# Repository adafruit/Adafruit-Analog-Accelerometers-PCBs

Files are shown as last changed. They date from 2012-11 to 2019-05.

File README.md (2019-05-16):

# PCBs for the Adafruit Analog Accelerometers - ADXL335, ADXL377 and ADXL326

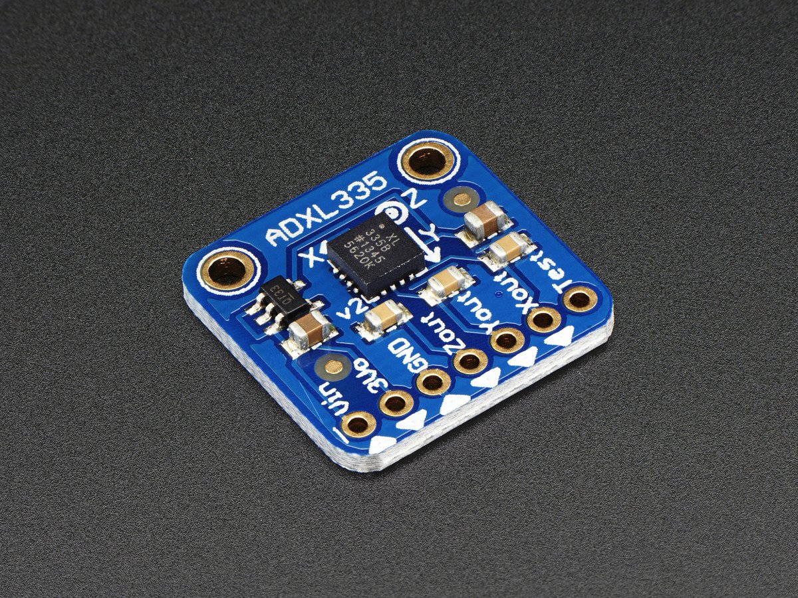
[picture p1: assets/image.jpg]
<a href="http://www.adafruit.com/products/163"><br/>Click here to purchase one from the Adafruit shop</a>

* [ADXL335 - 5V ready triple-axis accelerometer (+-3g analog out)](https://www.adafruit.com/products/163)
* [ADXL326 - 5V ready triple-axis accelerometer (+-16g analog out)](https://www.adafruit.com/product/1018)
* [ADXL377 - High-G Triple-Axis Accelerometer (+-200g Analog Out)](https://www.adafruit.com/product/1413)

We've updated our favorite triple-axis accelerometer to now have an on-board 3.3V regulator - making it a perfect choice for interfacing with a 5V microcontroller such as the Arduino. This breakout comes with 3 analog outputs for X, Y and Z axis measurements on a 0.75"x0.75" breakout board. The ADXL335 is the latest and greatest from Analog Devices, known for their exceptional quality MEMS devices. The VCC takes up to 5V in and regulates it to 3.3V with an output pin. The analog outputs are ratiometric: that means that 0g measurement output is always at half of the 3.3V output (1.65V), -3g is at 0v and 3g is at 3.3V with full scaling in between.

Fully assembled and tested. Comes with 8 pin 0.1" standard header in case you want to use it with a breadboard or perfboard. Two 2mm (0.08") mounting holes for easy attachment.

The XYZ filter capacitors are 0.1uF for a 50 Hz bandwidth

## License

Adafruit invests time and resources providing this open source design, 
please support Adafruit and open-source hardware by purchasing 
products from Adafruit!

Designed by Adafruit Industries.  
Creative Commons Attribution, Share-Alike license, check license.txt for more information
All text above must be included in any redistribution

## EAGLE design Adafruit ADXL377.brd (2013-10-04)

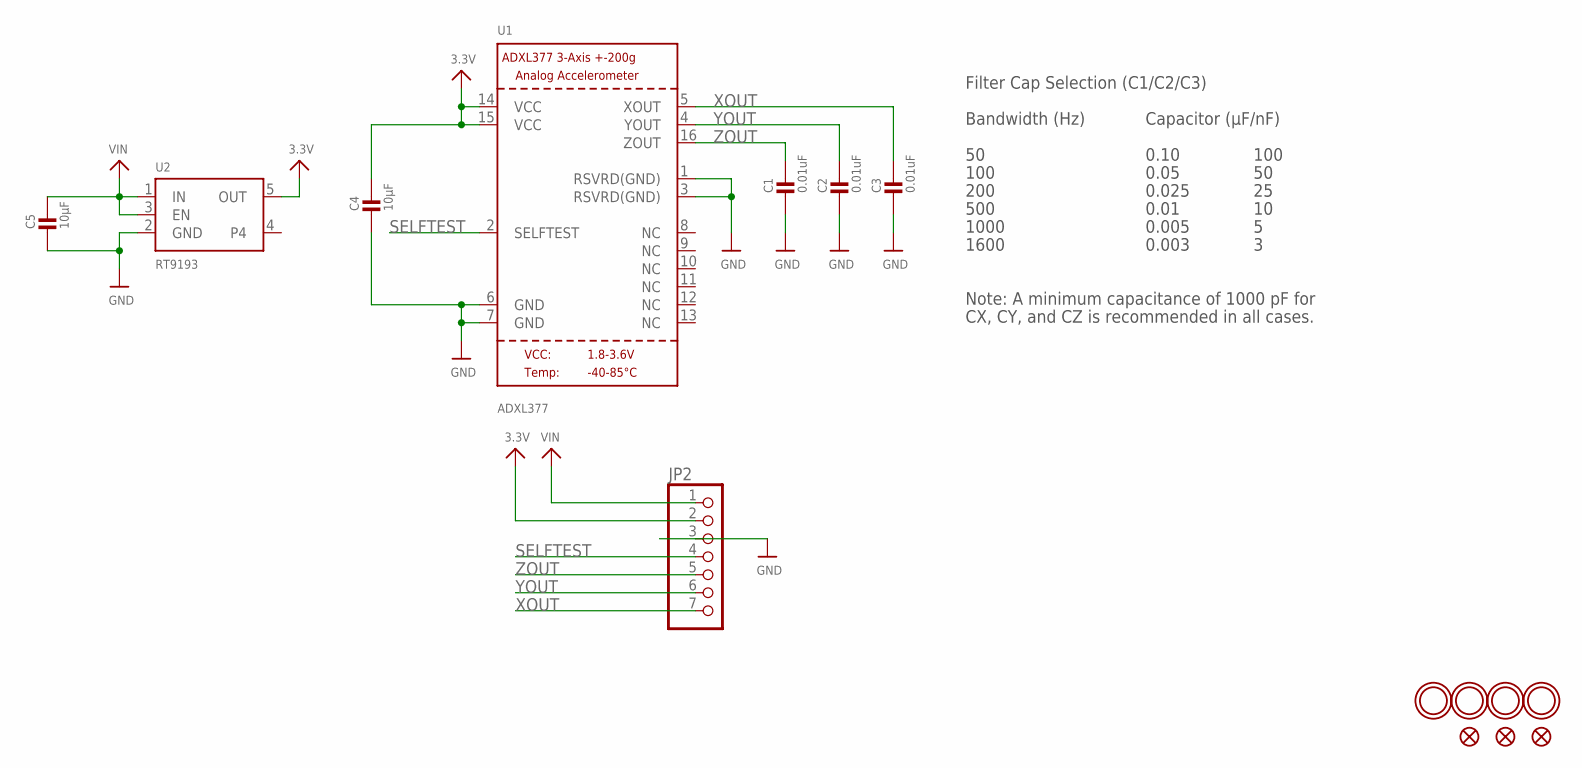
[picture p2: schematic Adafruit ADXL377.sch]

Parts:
C1, C2, C3: 0.01uF; _0805
C4, C5: 10µF; _0805
FID1, FID2, FID3: FIDUCIAL""; FIDUCIAL_1MM
JP2: HEADER-1X770MIL; 1X07_ROUND_70
U1: ADXL377; LFCSP16_LQ
U2: RT9193; SOT23-5
U$2, U$3, U$17, U$18: MOUNTINGHOLE2.5; MOUNTINGHOLE_2.5_PLATED

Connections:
3.3V: C4.1, JP2.2, U1.14 (VCC), U1.15 (VCC), U2.5 (OUT)
GND: C1.2, C2.2, C3.2, C4.2, C5.2, JP2.3, U1.1 (RSVRD(GND)), U1.3 (RSVRD(GND)), U1.6 (GND), U1.7 (GND), U2.2 (GND)
SELFTEST: JP2.4, U1.2 (SELFTEST)
VIN: C5.1, JP2.1, U2.1 (IN), U2.3 (EN)
XOUT: C3.1, JP2.7, U1.5 (XOUT)
YOUT: C2.1, JP2.6, U1.4 (YOUT)
ZOUT: C1.1, JP2.5, U1.16 (ZOUT)

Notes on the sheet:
Filter Cap Selection (C1/C2/C3)
Bandwidth (Hz)
Capacitor (µF/nF)
100
200
500
1000
1600
0.10
0.05
0.025
0.01
0.005
0.003
Note: A minimum capacitance of 1000 pF for
CX, CY, and CZ is recommended in all cases.

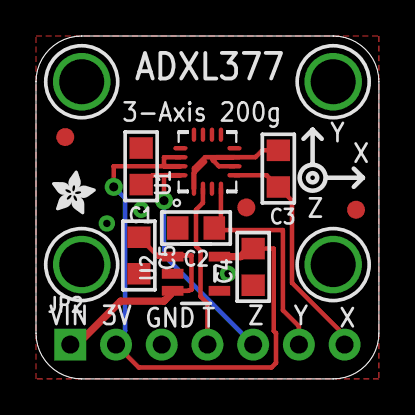
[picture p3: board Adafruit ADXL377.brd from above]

Board: 2 copper layers, 19.0 x 19.1 mm, 17 parts (1 on the bottom side), 7 nets.

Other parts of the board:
U$16, U$19: ADAFRUIT_2.5MM

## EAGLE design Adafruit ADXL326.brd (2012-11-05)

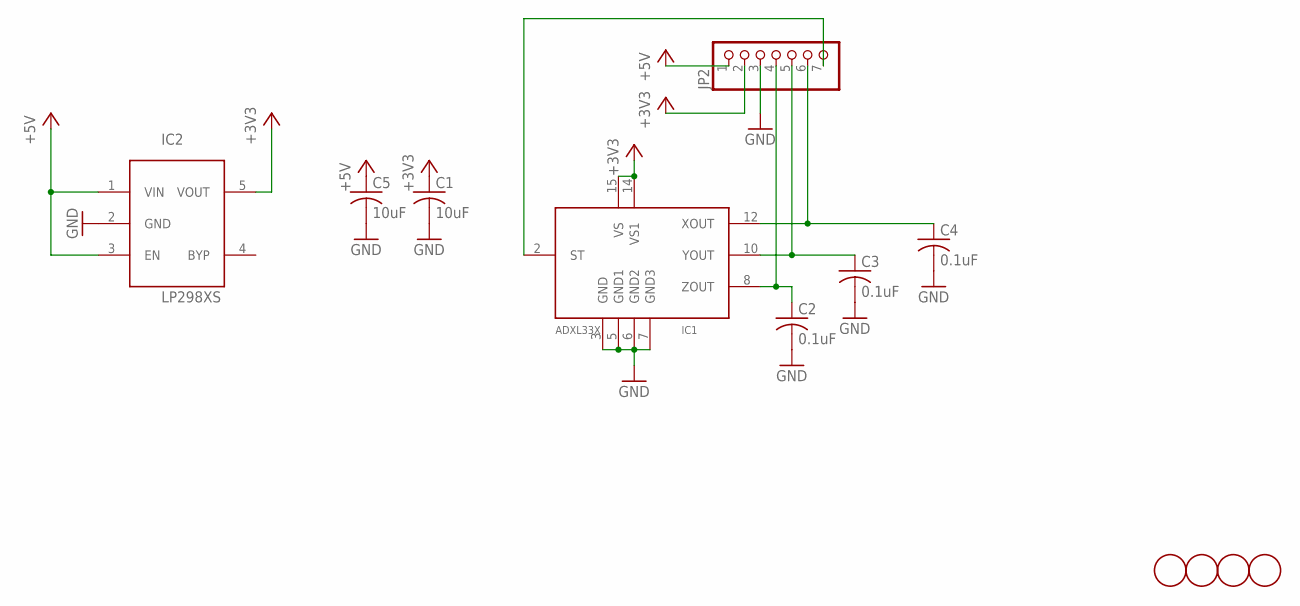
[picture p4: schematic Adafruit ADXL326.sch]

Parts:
C1, C5: 10uF; C0805K
C2, C3, C4: 0.1uF; C0805K
IC1: ADXL33X; 16LCSP
IC2: LP298XS; SOT23-5L
JP2: HEADER-1X7THICKER; 1X07_ROUND_76
U$1, U$2: FIDUCIAL; FIDUCIAL_1MM
U$5, U$8: MOUNTINGHOLE2.0; MOUNTINGHOLE_2.0_PLATED

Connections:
+3V3: C1.1, IC1.14 (VS1), IC1.15 (VS), IC2.5 (VOUT), JP2.2
+5V: C5.1, IC2.1 (VIN), IC2.3 (EN), JP2.1
GND: C1.2, C2.2, C3.2, C4.2, C5.2, IC1.3 (GND), IC1.5 (GND1), IC1.6 (GND2), IC1.7 (GND3), IC2.2 (GND), JP2.3
ST: IC1.2 (ST), JP2.7
XOUT: C4.1, IC1.12 (XOUT), JP2.6
YOUT: C3.1, IC1.10 (YOUT), JP2.5
ZOUT: C2.1, IC1.8 (ZOUT), JP2.4

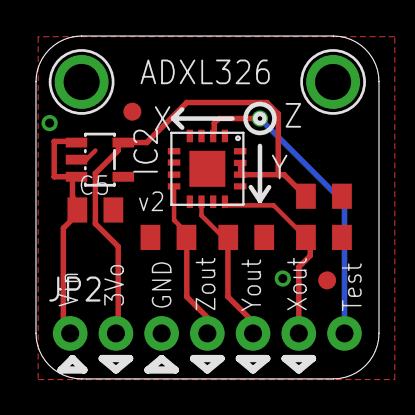
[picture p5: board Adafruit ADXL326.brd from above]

Board: 2 copper layers, 19.1 x 19.1 mm, 13 parts (1 on the bottom side), 7 nets.

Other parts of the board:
U$4: ADAFRUIT_2.5MM

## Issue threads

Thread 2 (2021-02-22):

cant open files... PCB program says error in file

soundtechscott, 2021-02-22:
none of these files open properly

can I have a raw text output version that I can paste into a file and rename as brd so my PCB program can open it?

looking for an adxl335

ladyada, 2021-02-22:
Eaglecad can open it, or you can import into kicad

soundtechscott, 2021-02-22:
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

it doesnt open...
sorry...
and Eagle is not free...
please save in a format that can be opened by other programs

soundtechscott, 2021-02-22:
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

Closed 2021-02-22.

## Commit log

2012-11-05 Eagle Cad for ADXL326 and ADXL335
    [Adafruit ADXL326.brd, Adafruit ADXL326.sch, Adafruit ADXL335.brd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]
2013-10-04 added adxl377
    [Adafruit ADXL377.brd, Adafruit ADXL377.sch]

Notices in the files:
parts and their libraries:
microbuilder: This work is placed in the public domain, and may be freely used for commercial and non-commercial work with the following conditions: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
